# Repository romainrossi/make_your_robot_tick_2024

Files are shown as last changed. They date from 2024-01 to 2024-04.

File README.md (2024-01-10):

# Make Your Robot Tick 2024

Make Your Robot Tick, a robotics competition by ESIGELEC and Muthoot.

# Asking Questions about the Competition

As a participating Team, if you have a question about the RuleBook or other aspect of the competition, you have to fill an issue in this repository.
1. Go to [Issues](../../issues)  and check if your question is already answered
2. If not, create a new issue with the "New Issue" button, and fill-in the form of the "RuleBook question" template.
3. The organisation team will shortly answer your question. Question and answer will be available for all teams.

# Soon

Soon, all the information for this robotics competition will be available here.
Follow this repository to be notified !

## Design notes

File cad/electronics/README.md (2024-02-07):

# Make Your Robot Tick - Electronics CAD files

This directory contains a KiCAD project for the electronic boards used on the game field.

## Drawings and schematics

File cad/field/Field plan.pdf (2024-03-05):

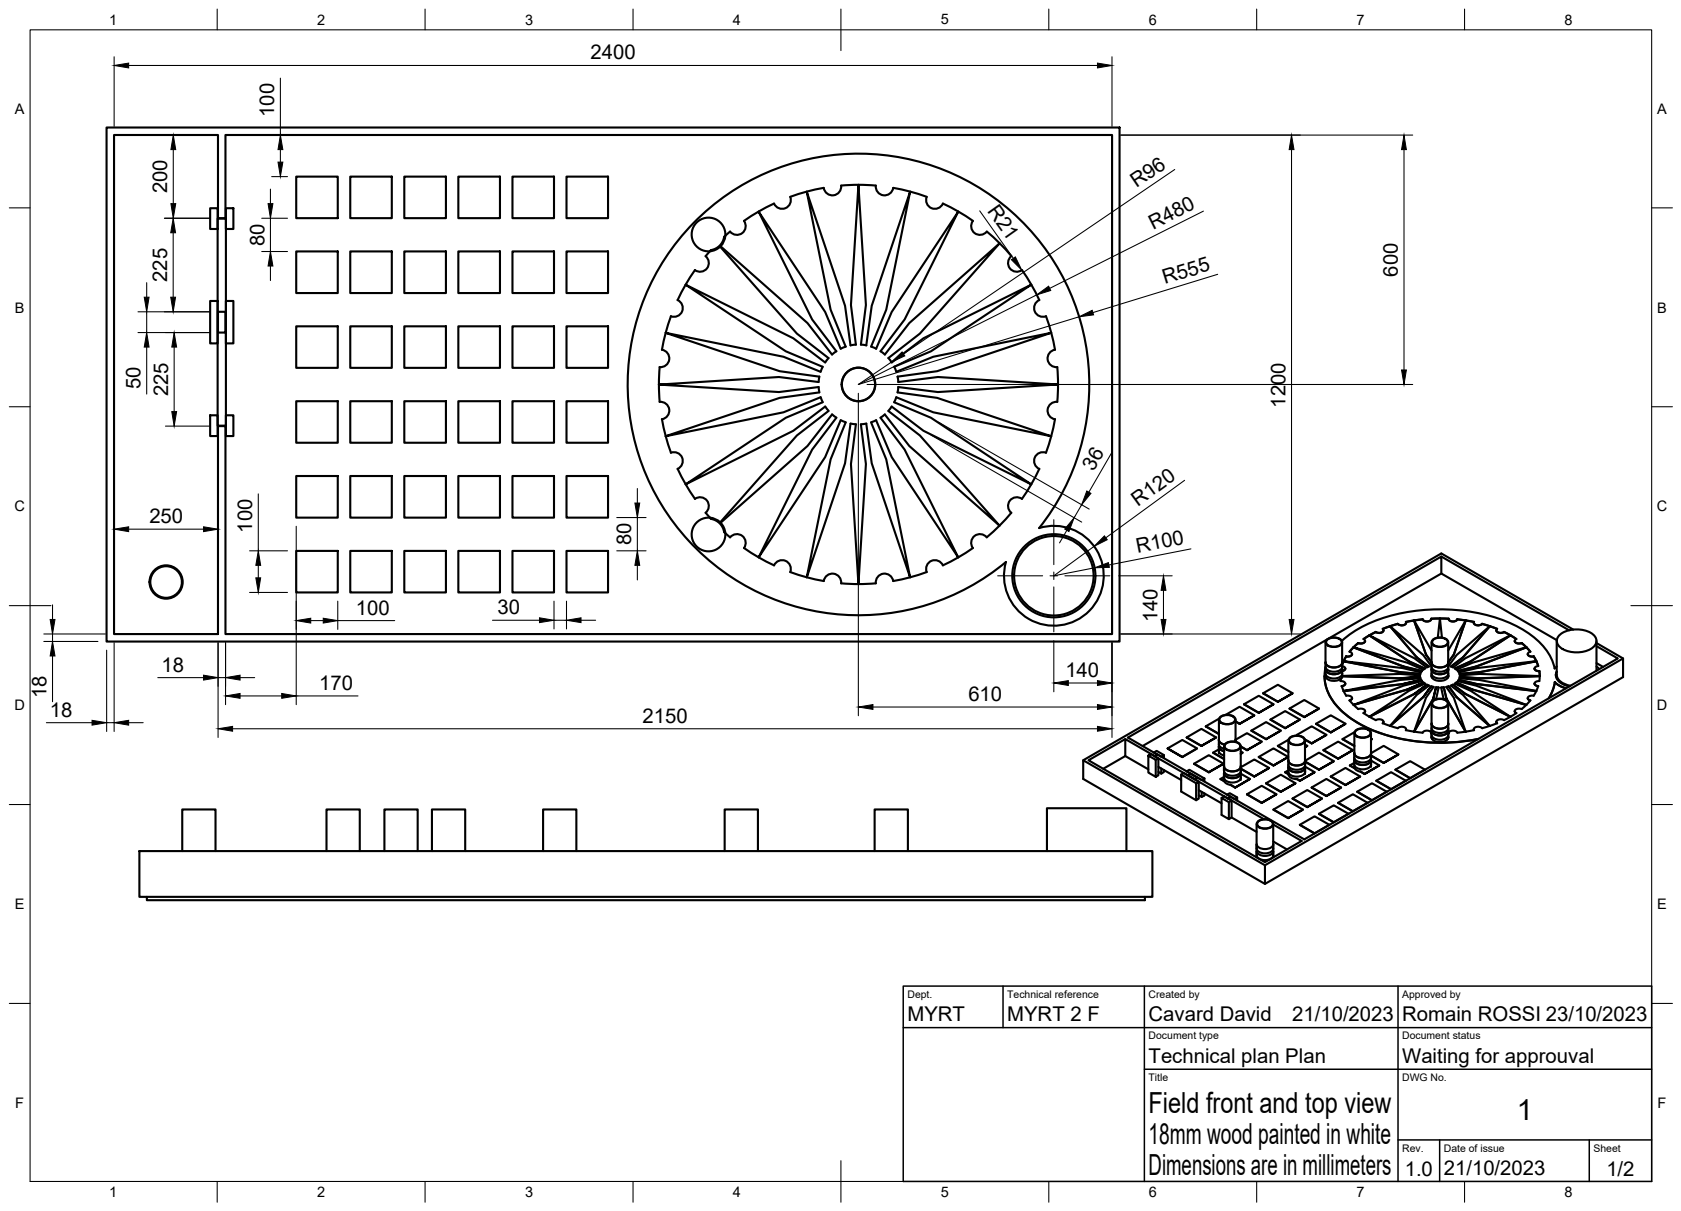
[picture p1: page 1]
Title; DWG No.; Rev.; Date of issue; Sheet; Dimensions are in millimeters; Field front and top view

Dept. MYRT | Technical reference MYRT 2 F | Created by Cavard David 21/10/2023 | Approved by Romain ROSSI 23/10/2023

Document type Technical plan Plan | Document status Waiting for approuval

18mm wood painted in white

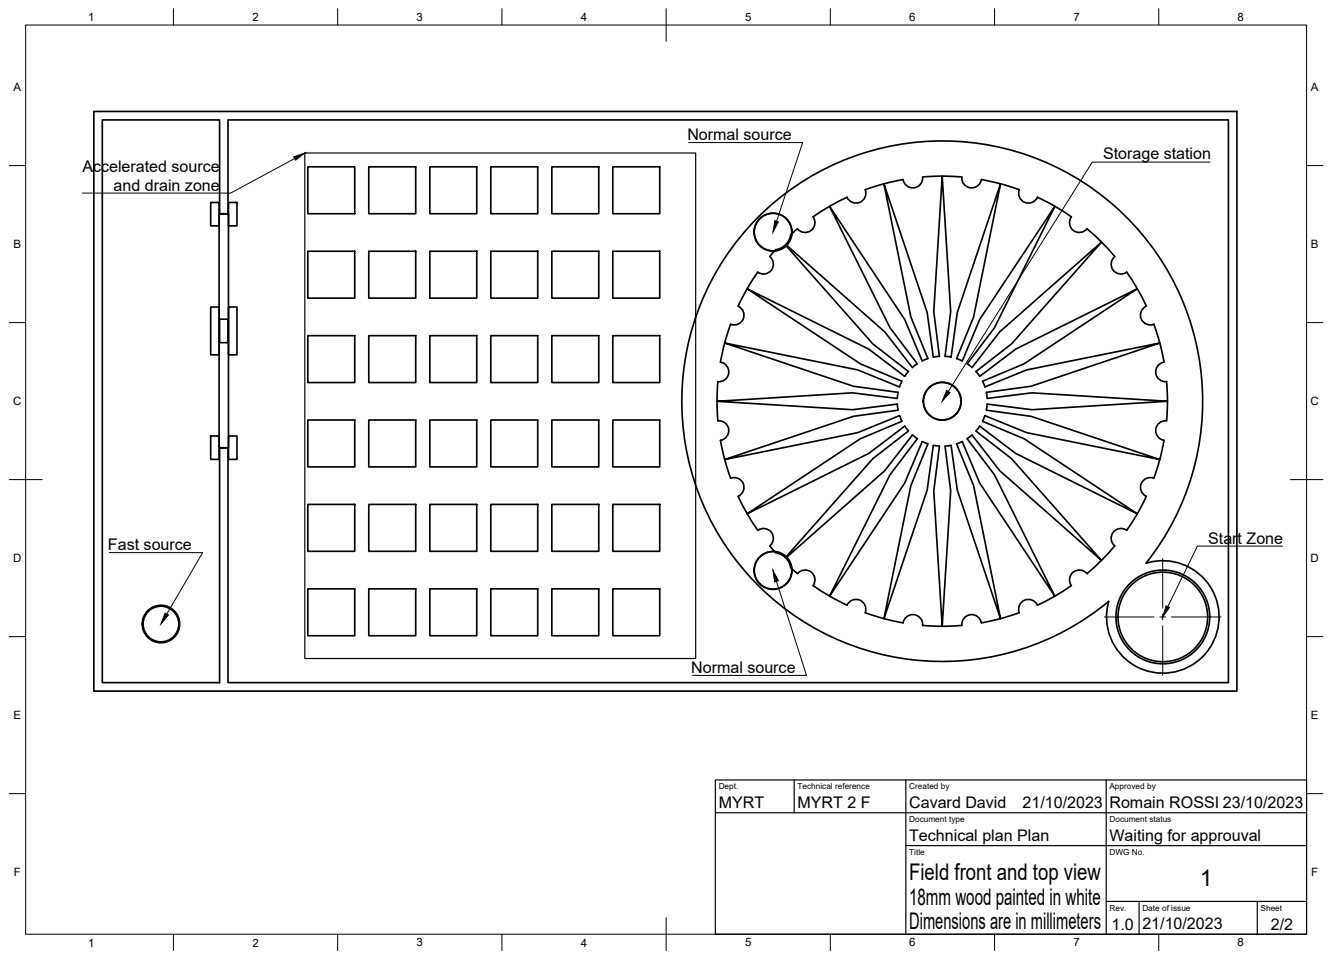
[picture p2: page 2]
Title; DWG No.; Rev.; Date of issue; Sheet; Dimensions are in millimeters; Field front and top view; Start Zone; Normal source; Fast source; Storage station

Accelerated source
and drain zone

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

Document type Technical plan Plan | Document status Waiting for approuval

18mm wood painted in white

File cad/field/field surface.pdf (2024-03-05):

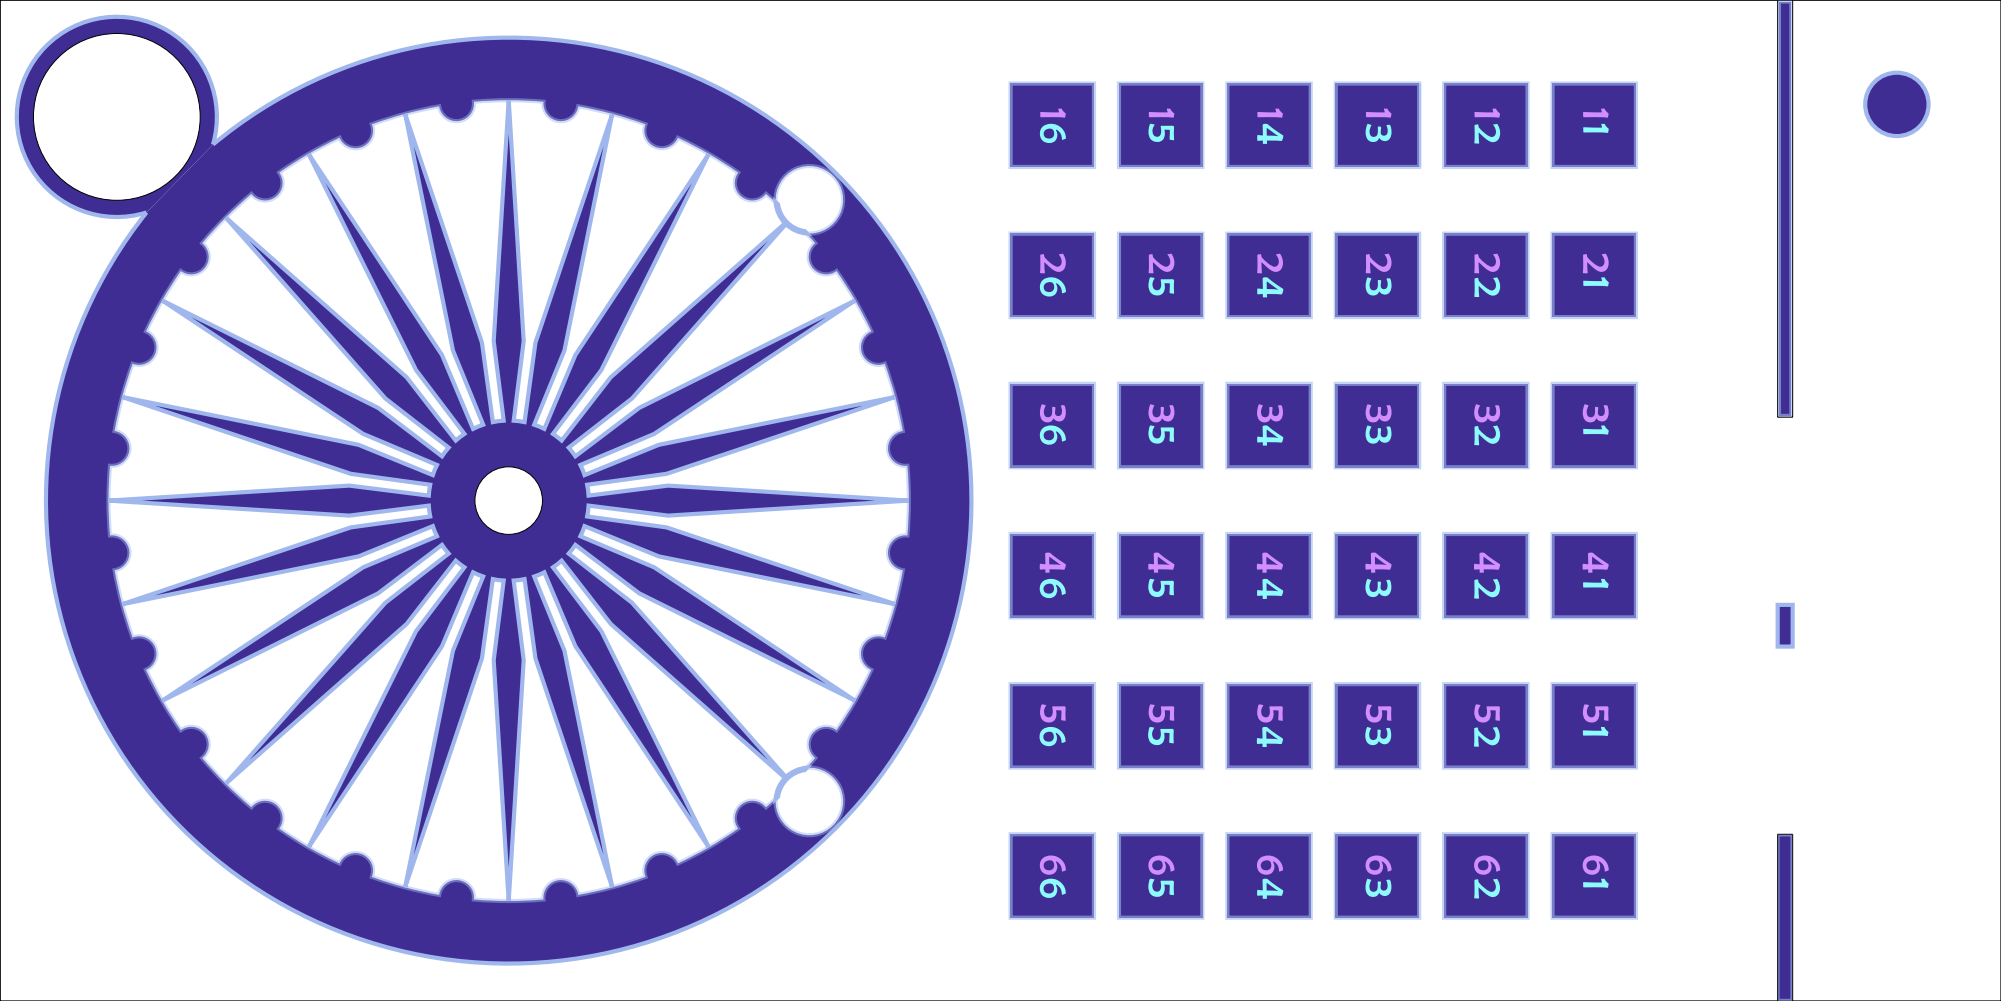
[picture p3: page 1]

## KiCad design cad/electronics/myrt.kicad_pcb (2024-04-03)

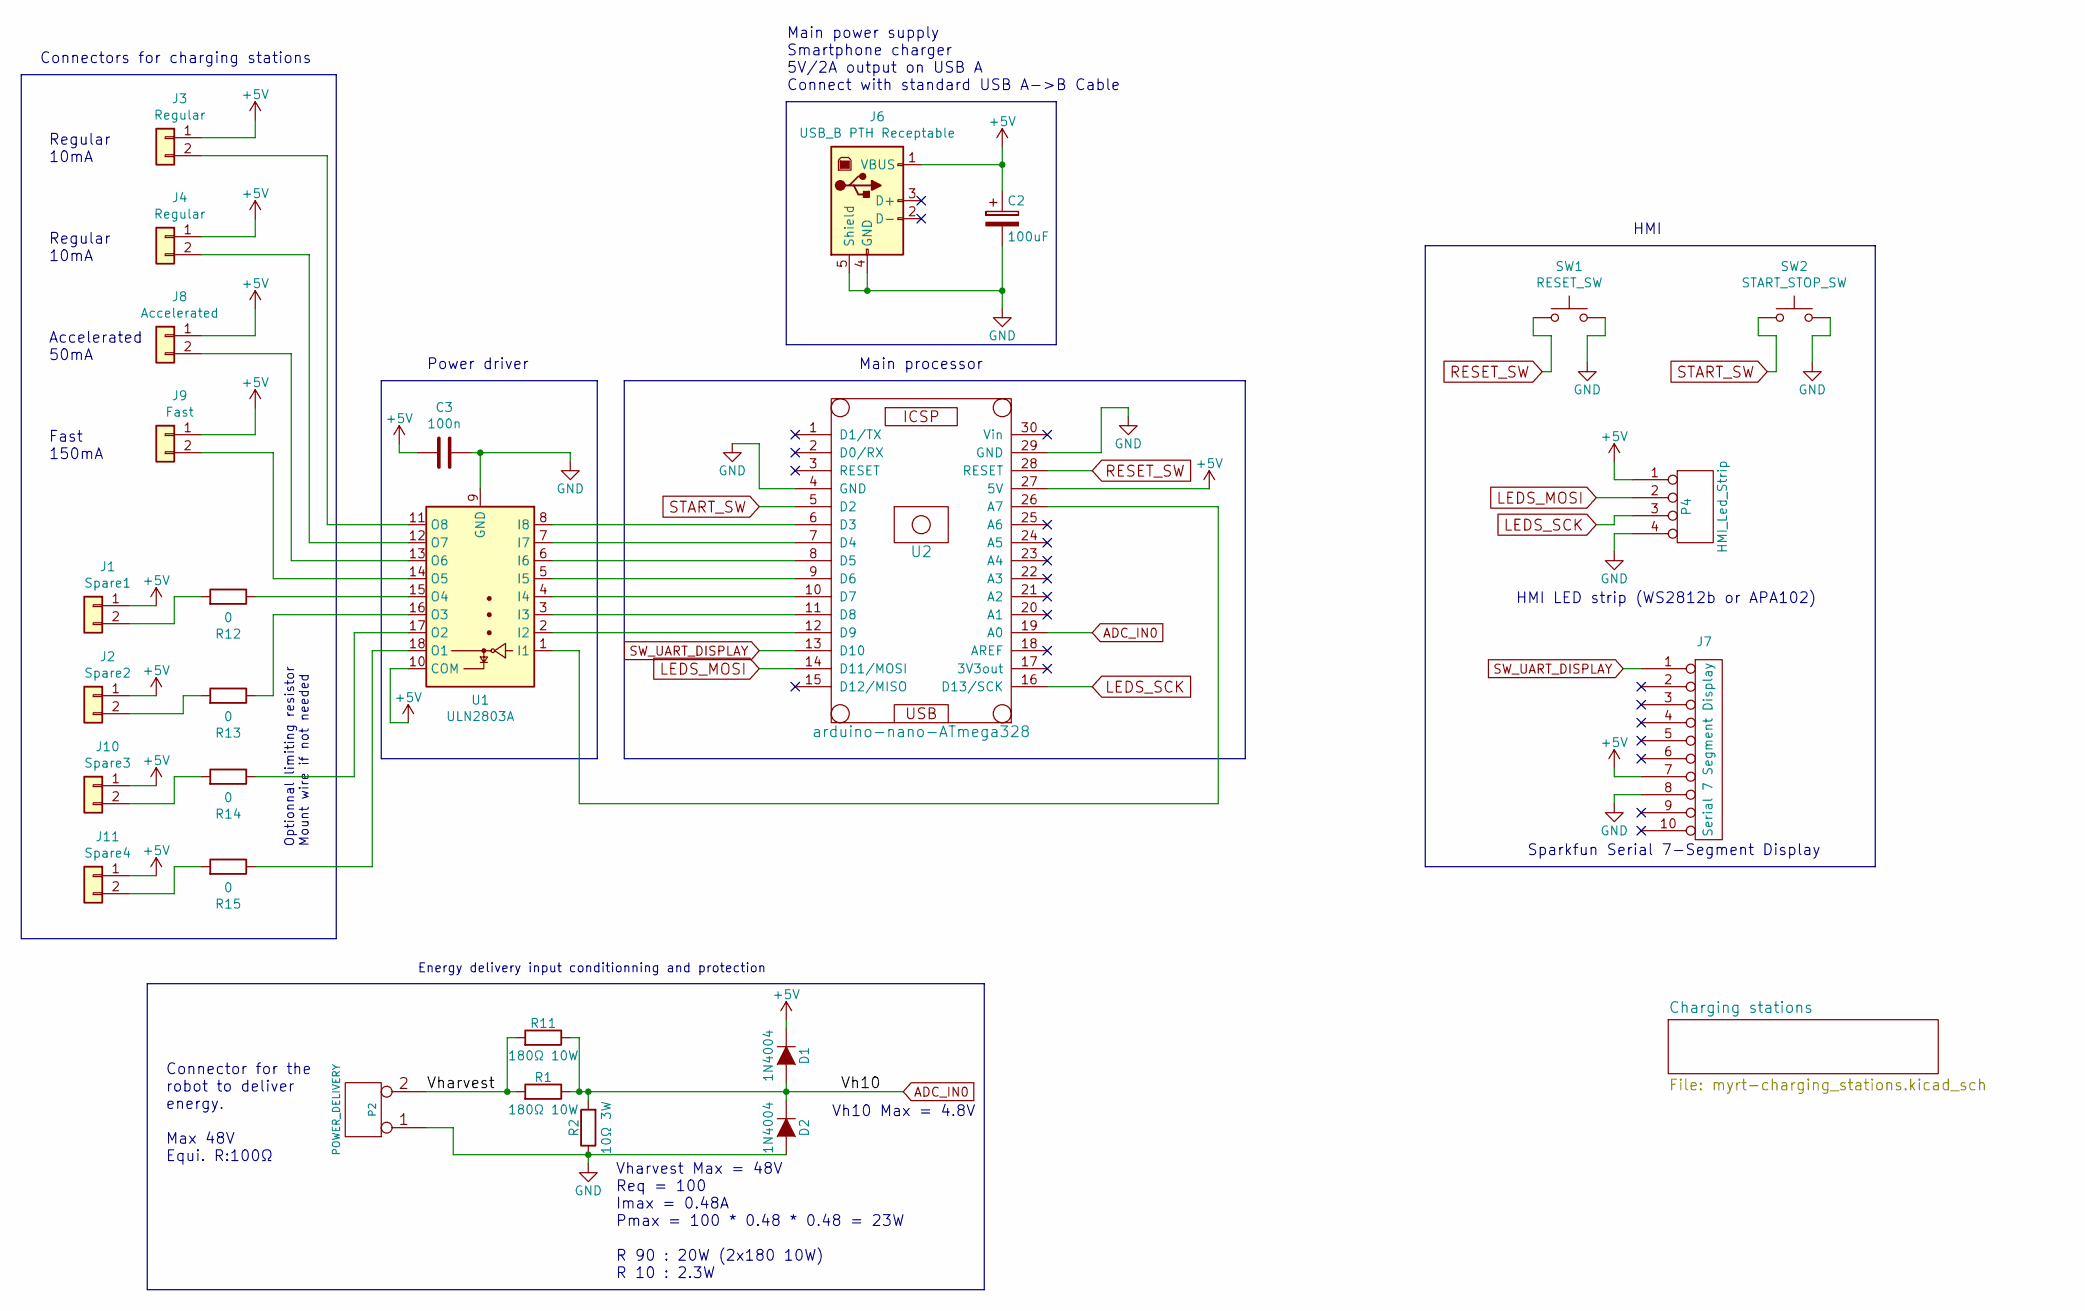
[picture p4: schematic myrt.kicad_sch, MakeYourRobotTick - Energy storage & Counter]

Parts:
C2: 100uF; CP_Radial_D10.0mm_P5.00mm
C3: 100n; C_Rect_L7.0mm_W2.5mm_P5.00mm
D1, D2: 1N4004; D_DO-41_SOD81_P12.70mm_Horizontal
J1: Spare1; PhoenixContact_MCV_1,5_2-G-3.5_1x02_P3.50mm_Vertical
J2: Spare2; PhoenixContact_MCV_1,5_2-G-3.5_1x02_P3.50mm_Vertical
J3, J4: Regular; PhoenixContact_MCV_1,5_2-G-3.5_1x02_P3.50mm_Vertical
J6: USB_B PTH Receptable; USB_B_OST_USB-B1HSxx_Horizontal
J7: Serial 7 Segment Display; PinSocket_1x10_P2.54mm_Vertical
J8: Accelerated; PhoenixContact_MCV_1,5_2-G-3.5_1x02_P3.50mm_Vertical
J9: Fast; PhoenixContact_MCV_1,5_2-G-3.5_1x02_P3.50mm_Vertical
J10: Spare3; PhoenixContact_MCV_1,5_2-G-3.5_1x02_P3.50mm_Vertical
J11: Spare4; PhoenixContact_MCV_1,5_2-G-3.5_1x02_P3.50mm_Vertical
P2: POWER_DELIVERY; PhoenixContact_MCV_1,5_2-G-3.5_1x02_P3.50mm_Vertical
P4: HMI_Led_Strip; PinSocket_1x04_P2.54mm_Vertical
R1, R11: 180Ω 10W; R_Axial_Power_L48.0mm_W12.5mm_P55.88mm
R2: 10Ω 3W; R_Axial_DIN0516_L15.5mm_D5.0mm_P25.40mm_Horizontal
R12, R13, R14, R15: 0; R_Axial_DIN0207_L6.3mm_D2.5mm_P15.24mm_Horizontal
SW1: RESET_SW; SW_PUSH-12mm_Wuerth-430476085716
SW2: START_STOP_SW; SW_PUSH-12mm_Wuerth-430476085716
U1: ULN2803A; DIP-18_W7.62mm_Socket_LongPads
U2: arduino-nano-ATmega328; Arduino_Nano

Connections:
+5V: C2.1, C3.2, D1.1 (K), J1.1, J2.1, J3.1, J4.1, J6.1 (VBUS), J7.7, J8.1, J9.1, J10.1, J11.1, P4.1, U1.10 (COM), U2.27 (5V)
/Vharvest: P2.2, R1.2, R11.2
ADC_IN0: D1.2 (A), D2.1 (K), R1.1, R2.2, R11.1, U2.19 (A0)
GND: C2.2, C3.1, D2.2 (A), J6.4 (GND), J6.5 (Shield), J7.8, P2.1, P4.4, R2.1, SW1.2, SW2.2, U1.9 (GND), U2.4 (GND), U2.29 (GND)
LEDS_MOSI: P4.2, U2.14 (D11/MOSI)
LEDS_SCK: P4.3, U2.16 (D13/SCK)
unnamed: J1.2, R12.2
unnamed: J2.2, R13.2
unnamed: J3.2, U1.11 (O8)
unnamed: J4.2, U1.12 (O7)
unnamed: J8.2, U1.13 (O6)
unnamed: J9.2, U1.14 (O5)
unnamed: J10.2, R14.2
unnamed: J11.2, R15.2
unnamed: R12.1, U1.15 (O4)
unnamed: R13.1, U1.16 (O3)
unnamed: R14.1, U1.17 (O2)
unnamed: R15.1, U1.18 (O1)
unnamed: U1.1 (I1), U2.26 (A7)
unnamed: U1.2 (I2), U2.12 (D9)
unnamed: U1.3 (I3), U2.11 (D8)
unnamed: U1.4 (I4), U2.10 (D7)
unnamed: U1.5 (I5), U2.9 (D6)
unnamed: U1.6 (I6), U2.8 (D5)
unnamed: U1.7 (I7), U2.7 (D4)
unnamed: U1.8 (I8), U2.6 (D3)
RESET_SW: SW1.1, U2.28 (RESET)
START_SW: SW2.1, U2.5 (D2)
SW_UART_DISPLAY: J7.1, U2.13 (D10)

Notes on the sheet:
Connector for the robot to deliver energy. Max 48V Equi. R:100Ω
Energy delivery input conditionning and protection
Optionnal limiting resistor Mount wire if not needed
Vharvest Max = 48V Req = 100 Imax = 0.48A Pmax = 100 * 0.48 * 0.48 = 23W R 90 : 20W (2x180 10W) R 10 : 2.3W
HMI
Main power supply Smartphone charger 5V/2A output on USB A Connect with standard USB A->B Cable
Power driver
Vh10 Max = 4.8V
Connectors for charging stations
Sparkfun Serial 7-Segment Display
HMI LED strip (WS2812b or APA102)
Accelerated 50mA
Regular 10mA
Fast 150mA
Main processor

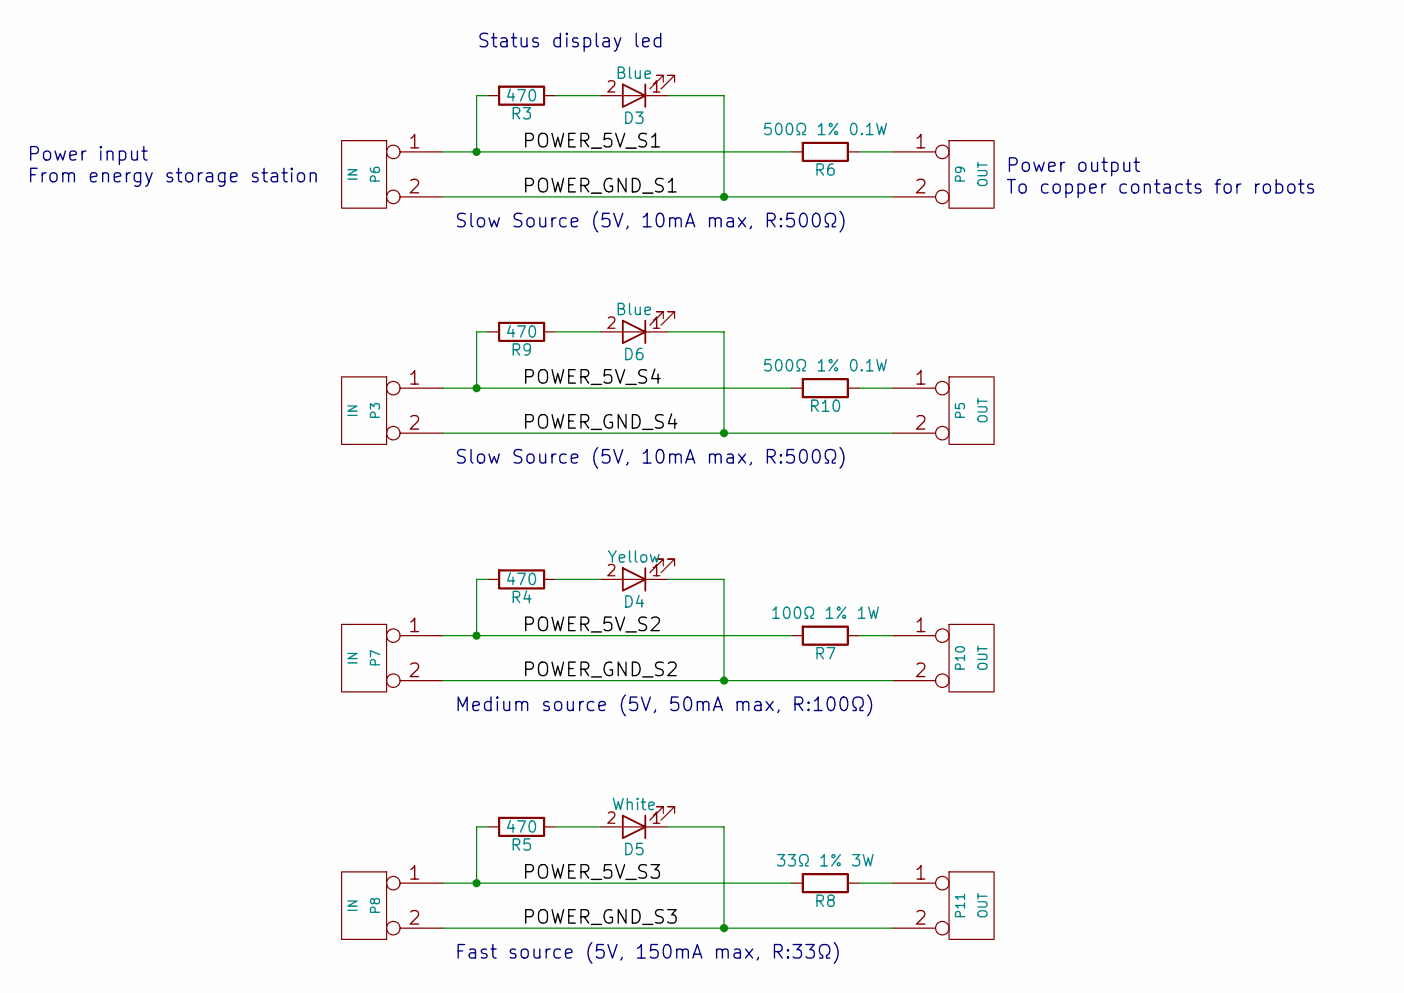
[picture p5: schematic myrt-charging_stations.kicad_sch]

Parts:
D3, D6: Blue; LED_D5.0mm
D4: Yellow; LED_D5.0mm
D5: White; LED_D5.0mm
P3, P6, P7, P8: IN; PhoenixContact_MCV_1,5_2-G-3.5_1x02_P3.50mm_Vertical
P5, P9, P10, P11: OUT; PinSocket_1x02_P2.54mm_Vertical
R3, R4, R5, R9: 470; R_Axial_DIN0207_L6.3mm_D2.5mm_P10.16mm_Horizontal
R6, R10: 500Ω 1% 0.1W; R_Axial_DIN0207_L6.3mm_D2.5mm_P15.24mm_Horizontal
R7: 100Ω 1% 1W; R_Axial_DIN0516_L15.5mm_D5.0mm_P25.40mm_Horizontal
R8: 33Ω 1% 3W; R_Axial_DIN0614_L14.3mm_D5.7mm_P25.40mm_Horizontal

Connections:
/Charging stations/POWER_5V_S1: P6.1, R3.2, R6.2
/Charging stations/POWER_5V_S2: P7.1, R4.2, R7.2
/Charging stations/POWER_5V_S3: P8.1, R5.2, R8.2
/Charging stations/POWER_5V_S4: P3.1, R9.2, R10.2
/Charging stations/POWER_GND_S1: D3.1 (K), P6.2, P9.2
/Charging stations/POWER_GND_S2: D4.1 (K), P7.2, P10.2
/Charging stations/POWER_GND_S3: D5.1 (K), P8.2, P11.2
/Charging stations/POWER_GND_S4: D6.1 (K), P3.2, P5.2
unnamed: D3.2 (A), R3.1
unnamed: D4.2 (A), R4.1
unnamed: D5.2 (A), R5.1
unnamed: D6.2 (A), R9.1
unnamed: P5.1, R10.1
unnamed: P9.1, R6.1
unnamed: P10.1, R7.1
unnamed: P11.1, R8.1

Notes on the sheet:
Slow Source (5V, 10mA max, R:500Ω)
Medium source (5V, 50mA max, R:100Ω)
Status display led
Power output To copper contacts for robots
Power input From energy storage station
Fast source (5V, 150mA max, R:33Ω)

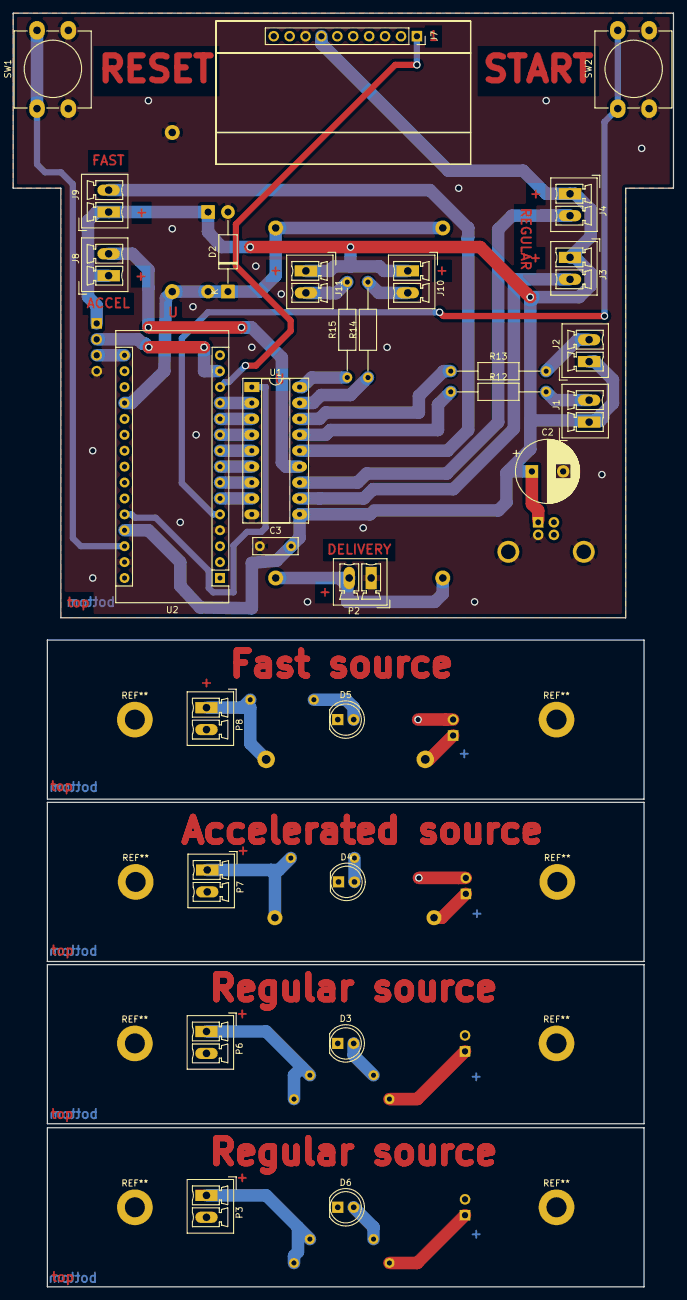
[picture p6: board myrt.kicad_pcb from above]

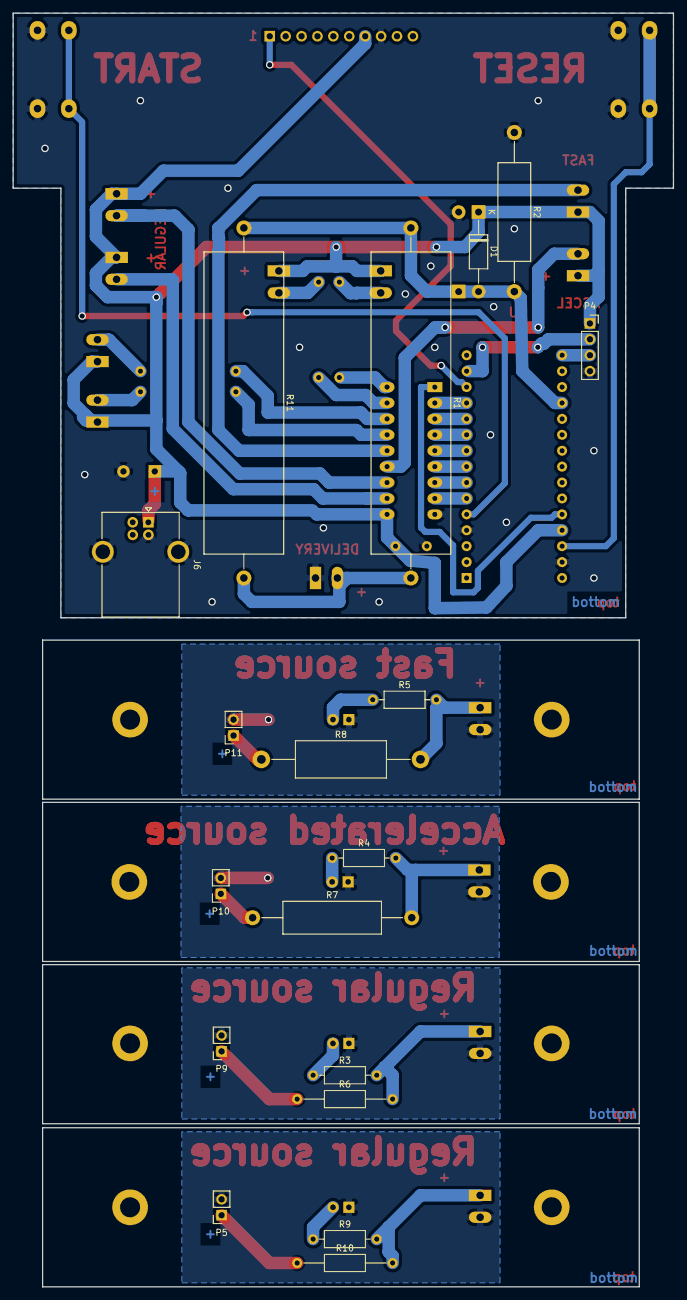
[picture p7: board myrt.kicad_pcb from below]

Board: 2 copper layers, 105.4 x 203.3 mm, 47 parts (18 on the bottom side), 45 nets.

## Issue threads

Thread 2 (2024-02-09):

Need clarification about MYRT Competition

Surriya1010, 2024-02-09:
Team Name : FENESTA
RuleBook Reference : nil
Question :

1.  Do we have any specific Discharge rate/Waveform ,while discharging to the Energy collector from the Robot
2.  Do we have specified charging voltage (like 6v, 12v) in the Charging Source, For the waveform given (Fast, Middle and  Slow Energy Sources)

romainrossi, 2024-02-09:
### Answer to @Surriya1010 , question 1

To deliver energy to the counter and scores points, you robot must establish contact with the "Energy Storage Station" described in the Rulebook, page 12.
The contacts dimension and position are described page 10 (same height for Energy Storage Station and Sources).

When delivering energy, your robot energy storage system will discharge through a resistor of 100Ω. The voltage across this resistor will be monitored by the Energy Storage Station to measure the corresponding current, count the energy quantity and score points.

I added all the electrical schematics (made with KiCAD) in the repository : [schematics](/cad/electronics).

Here is an extract of this schematics showing the energy delivery part :
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

As per the safety rules, your robot must not deliver above 48V to this point.

romainrossi, 2024-02-09:
### Answer to @Surriya1010 , question 2

Every source delivers 5V across a limiting resistor.

The full schematics are also available in the repository (see link in previous answer), here is an extract showing only the sources :
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

Each source is enabled/disabled following the waveform given in the Rulebook, page 11, figure 5.

To gather energy, your robot has to make contact with the sources on the field and charge it's embedded energy storage system.

devalopr, 2024-06-18:
"Power input
From energy storage station"

@romainrossi
What's the source for 5V?
A battery?
A 5V 1A power supply? [[Like this](https://robu.in/product/orange-5v-1a-power-supply-with-5-5mm-dc-plug-adapter/?gad_source=1)]

romainrossi, 2024-06-18:
The power supply for the Power Sources on the field will be a 5V USB phone charger or USB Power bank, depending on the installation conditions. The power rating will be well above what is needed to power the whole system.

As you can see in the schematics above, your robot can charge on each source through a current-limiting resistor which value is different for each source rating.
As a consequence, the maximum voltage your robot can get on the sources is about 5V (+/- power supply tolerance), but this voltage will decrease as your robot draw more current to charge it's Energy Storage System.

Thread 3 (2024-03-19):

Some Clarifications

Alfonztb, 2024-03-19:
TEAM NAME: BASILISK

1. Will we get points if our robot makes contact with the charging station even if it is not active at that given instant of time?
2. Are we allowed to modify or update the code in our robot, after each round?
3. We are facing an error 'Expecting pts ' while trying to open the file mart.kicad_pcb. Can you do the needful?
4. Is there a limit on the energy storage capacity of the robot?

romainrossi, 2024-04-03:
1. Yes, as per the Rulebook section 5.1.2, your team will score points for each connections to a charging station regardless of the source activation state at this time.
2. Yes, you are allowed to change the code of your robot between each match. Pay attention to present your robot on time for the following match or you can be disqualified. You can also make hardware modification, in that case you will need to ask for a Robot Review to be performed by a referee before being allowed to proceed with your next match.
3. Sorry for the inconvenience, I will check that and publish an update ASAP.
4. No. However your robot will be limited by the energy available from the sources as it is forbidden to gather energy from another source than the Energy Sources on the field.

romainrossi, 2024-04-03:
The PCB File has been replaced by the backup, this should work now. Thank you for reporting this issue.

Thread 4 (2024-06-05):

Energy to Score Conversion

spiceybolt, 2024-06-05:
Team Name : Technocats
RuleBook Reference : nil
Question : How exactly is the voltage measured in the energy storage station converted to points ?

romainrossi, 2024-06-05:
The Energy Storage Station measures the voltage across a power resistor at a high frequency and deduce the corresponding instantaneous power delivered using Ohms law (P=RxI²). You can see the schematics for the details on this part.

This instantaneous power is summed during the whole duration of the match to keep the raw energy value.
This raw energy value is divided by a calibrated constant value to convert it to points, which are displayed at all time during the match on the energy storage station display.

To ensure fare competition across the two fields which will be used during the match, the raw value of energy delivered is divided by a calibrated constants. This calibration procedure will be done by the referee before each rounds of match.

The calibration procedure is done in the objective that a robot can score a maximum of 100 points if it gather all the energy delivered by the sources on the same field. This will ensure that slights differences in the energy delivered by same sources (across the two fields) are irrelevant.

A training field, with calibrated Energy Storage Station will be made available to the teams for testing purposes.

spiceybolt, 2024-06-05:
> This instantaneous power is summed during the whole duration of the match to keep the raw energy value.
This raw energy value is divided by a calibrated constant value to convert it to points, which are displayed at all time during the match on the energy storage station display.

Would the score be equal when the voltage reading from the energy storage station is taken in an instant compared to the voltage reading measured continuously until the energy storage system of the robot is depleted ?

romainrossi, 2024-06-06:
The measurement done by the Energy Storage Station is an **energy** quantity (Joule or Wh), not a tension.
This measurement is processed from instantaneous current (deduced by measuring tension across a resistor) integrated over time.
The score is then processed by dividing the energy quantity delivered by the calibrated constant.

The robot must stay connected to the Energy Storage Station long enough to transfer a measurable energy quantity, otherwise it won't score any points.

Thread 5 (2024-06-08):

[RuleBook] -

Alfonztb, 2024-06-08:
* Team Name : BASILISK
* Question: In the circuit diagram provided, there were 5 chipboards. Should we print it onto a single board or should we print it onto different boards?

romainrossi, 2024-06-09:
Assuming you are referring to the schematics of the Energy Sources which are located on the field, the provided circuit design is printed on a single PCB, then cut into multiple small boards (1 board for each source).
If you plan to build your own system, you can however print each board separately as you wish.

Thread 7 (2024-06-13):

[RuleBook] - Width of the door passageway

devalopr, 2024-06-13:
* Team Name : maxq
* RuleBook Reference : page 9 / figure 2
* Question : What's the width of the passageway through the door? The door guiderails seem to extend into the passageway, reducing the width of the passageway from 225mm as dimensioned in the pdf down to 170mm. Can you please confirm? Providing us with the 3D model of the arena would also work

devalopr, 2024-06-13:
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

I estimated the door width using CAD. If it's actually 170mm, I would suggest increasing it to at least 200mm if possible. Because, even a Turtlebot with 178mm width wont be able to pass through the door

romainrossi, 2024-06-14:
Very good remark, the current opening dimension of the door is not correctly specified.

Taking your suggestion, we decided  to build the door and field in such a way to guarantee an opening of at least 200mm for each door position.

wreckage0907, 2024-06-22:
> Taking your suggestion, we decided  to build the door and field in such a way to guarantee an opening of at least 200mm for each door position.

Sir please give us confirmation of the finalized door width and width of the passageway and possibly a field plan as we have to make modifications accordingly. If possible can it be more than 200mm as the current entrance width is too restrictive. We have made considerable progress with the design and the current constraints mean that we have to make a lot of modifications which is not possible within this given time frame .

romainrossi, 2024-06-25:
After discussion with the team responsible for the construction of the field, I can confirm the following information :
The door and walls will be build in a way to ensure a passageway of 225mm.

The flanges represented on the drawing will be part of the mobile door and as such will be removed for the opened door.

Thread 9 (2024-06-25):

[Final] - Surface of competition arena

spiceybolt, 2024-06-25:
* Team Name : Technocats
* Question: What will be the surface of the arena made of?

romainrossi, 2024-06-26:
The arena surface is a printed board. It has a smooth surface and will be placed on a plywood board to offer additional rigidity.

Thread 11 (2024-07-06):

[RuleBook] - Use of LIDAR

Alfonztb, 2024-07-06:
* Team Name : Basilisk
* RuleBook Reference : 3.1 General Information
* Question : Can we use LIDAR sensors in our robot??
*

romainrossi, 2024-07-06:
Yes. Any embedded sensor can be used.

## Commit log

2024-02-07 Added electronics schematics of Energy Storage Systems and Sources
    [myrt-charging_stations.kicad_sch, myrt-charging_stations.sch, myrt.kicad_pcb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]
2024-02-14 Updated source names to match with other documents (slow/medium/fast)
    [myrt-charging_stations.kicad_sch, myrt.kicad_sch]
2024-04-03 Corrected error "Expecting pts" on openning the Kicad PCB file (corrupted file)
    [myrt.kicad_pcb]
